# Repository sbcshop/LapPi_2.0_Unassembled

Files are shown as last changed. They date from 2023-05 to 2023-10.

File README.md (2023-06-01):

# LapPi_2.0_Unassembled


LapPi 2.0 - a 100% DIY modular laptop which is compatible with all single board computers. Now that's what we call a true Level-Up.

LapPi 2.0 is in its core is a superbly loaded computer, one of its kind and only one in such segment. Available in 5 bright (Clear, Red, Blue, Yellow and Black) and beautiful colors, LapPi 2.0 comes in assembled and un-assembled variants.

The users may choose any single board computer (SBC) for LapPi such as RockPi, Asus Tinker, BananaPI or RaspberryPi. Just connect the SBC and voilà.

LapPi 2.0 is available in 2 variants - **_Assembled_** and **_Unassembled_**. 

You can checkout Step by Step Guide for **_Assembled version of LapPi 2.0_ [here](https://github.com/sbcshop/LapPi_2.0_Assembled)** 

The unassembled version is a treat for our techie friends and electronic enthusiasts. As we mentioned, LapPi 2.0 is 100% 'Do It Yourself', you get all the components and parts in individual packing in a classy protective case. Assembly of the LapPi 2.0 is very easy.

### Box Content
- 13 x 3mm thick Acrylic Panels
- 02 x Hinges
- 02 x 8ohm Speakers
- 01 x Raspberry Pi Official 8MP NoIR Camera
- 01 x Micro USB Power Cable
- 01 x Type C Power Cable
- 01 x Micro HDMI Connector
- 02 x HDMI Connector
- 01 x HDMI Flex Cable
- 01 x 7 inch Full Touch Capacitive LCD
- 01 x UPS (without batteries)
- 01 x Wireless Keyboard
- 01 x Power Adapter
- 01 x Pack of Screws and Standoffs
- 01 x Protective Case

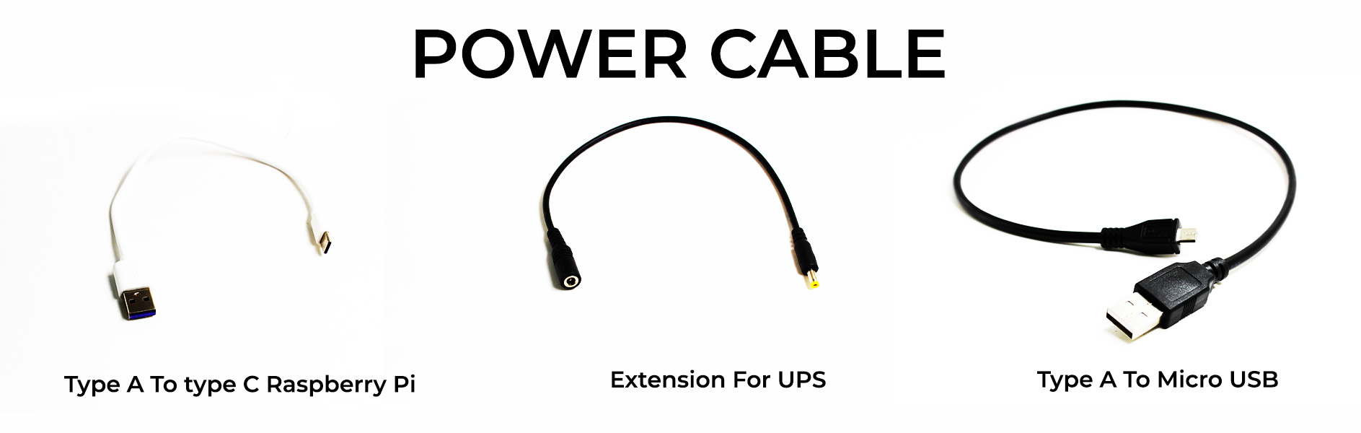
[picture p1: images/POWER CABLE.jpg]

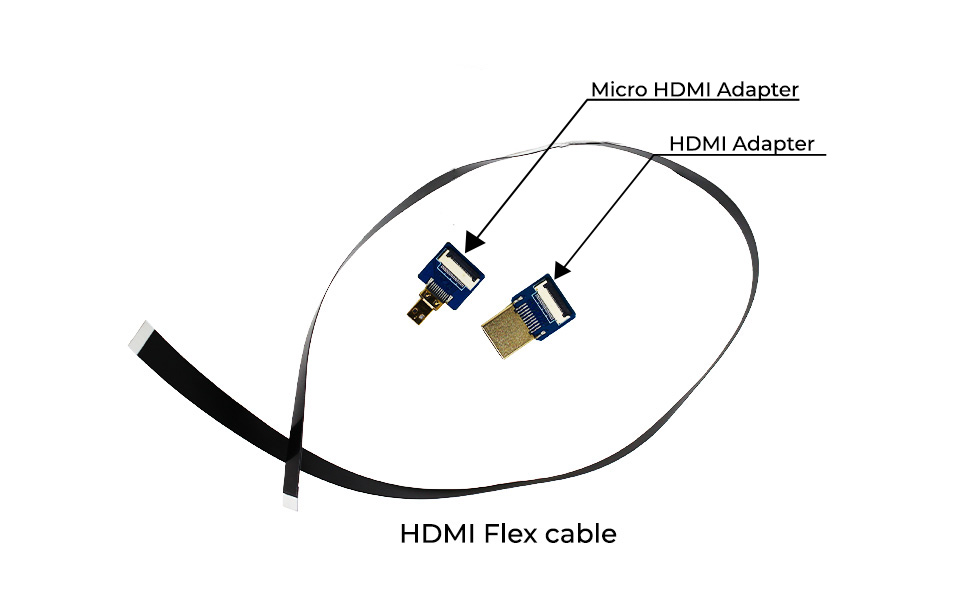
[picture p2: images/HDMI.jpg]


### Prepare HDMI Extension cable 


## Step 1: Setup Raspberry Pi
Before we begin assembling the LapPi, let us first set up the Raspberry Pi, which you may do by following the latest Online [Raspberry Pi Setup instructions](https://projects.raspberrypi.org/en/projects/raspberry-pi-setting-up)

Or [Click Here](https://github.com/sbcshop/LapPi_2.0_Unassembled/blob/main/Documents/Setting%20up%20your%20Raspberry%20Pi.pdf) to download a pdf of how to set up Pi.

## Step 2: Assembly Process
Before we proceed for assembly make sure you have below listed Screws, nuts and standoff in mentioned qty required for various section of LapPi assembly,

* For Body: (Qty - 28 set)
  * Screw - M3x10mm
  * Nut- M3
 
* For KeyBoard: (Qty - 5 set) 
  * Standoff - M3x12mm
  * Screw - M3x10mm
  * Nut - M3

* For Camera: (Qty - 4 set) 
  * Screw - M1.5x10mm
  * Nut - M1.5

* For Display: (Qty - 4 set) 
  * Standoff - M3x12mm
  * Screw - M3x10mm
  * Nut - M3

* For Raspberry Pi & UPS Hat: (Qty - 8 set) 
  * Standoff - M2.5x12mm
  * Screw - M2.5x10mm
  * Nut - M2.5

* For Speaker: (Qty - 8 set)
  * Standoff - M3x24mm
  * Nut - M3

* For Hinge : (Qty - 8 set)
  * Screw Self-Taping - M3x6mm

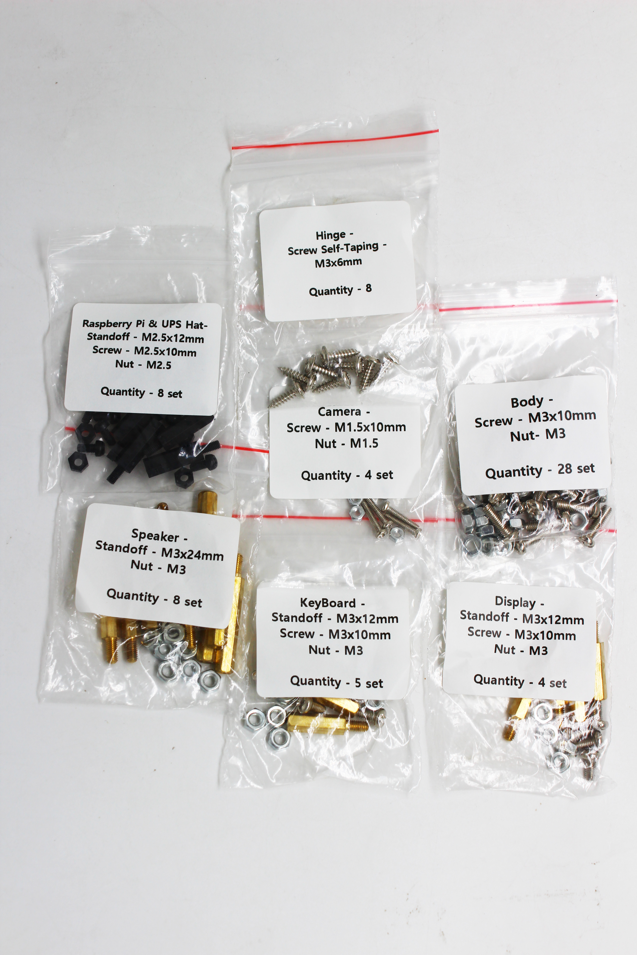
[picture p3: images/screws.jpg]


Checkout below demo to understand working with screw and nuts fitting,

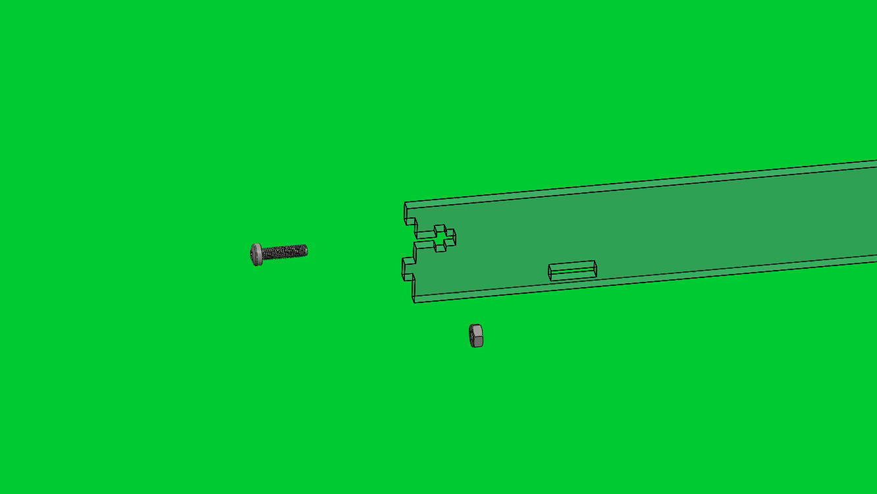
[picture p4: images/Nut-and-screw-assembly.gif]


### 1) LapPi 2.0 Base Part Assembly: 
- Here in base assembly section will be dealing with some acrylic body parts like Base plate and side layers, for this you will need M3x10mm Screw, M3 Nut
- First you will place UPS power and Raspberry Pi using mentioned sets of standoff, screw and nuts. 
- Next you will attach side layer plus support layer for keyboard.

Checkout demo below for better understanding how to achieve this section of assembly:

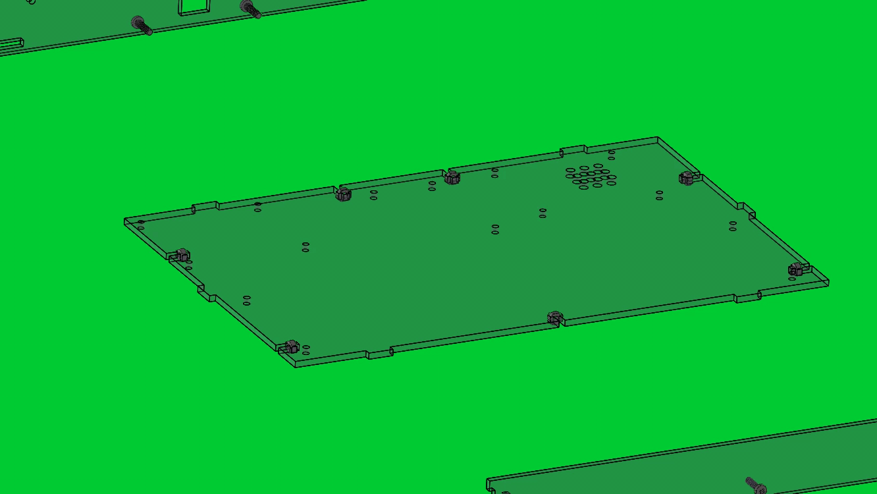
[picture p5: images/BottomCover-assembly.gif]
 

### 2) LapPi 2.0 Top Part Assembly:
- In this section will be dealing with display, camera and speaker fittings. 
- Again first take base support plate attach display and speaker.
- Then connect side layer plus top support layer on which camera will be attach  
So checkout below steps to follow,

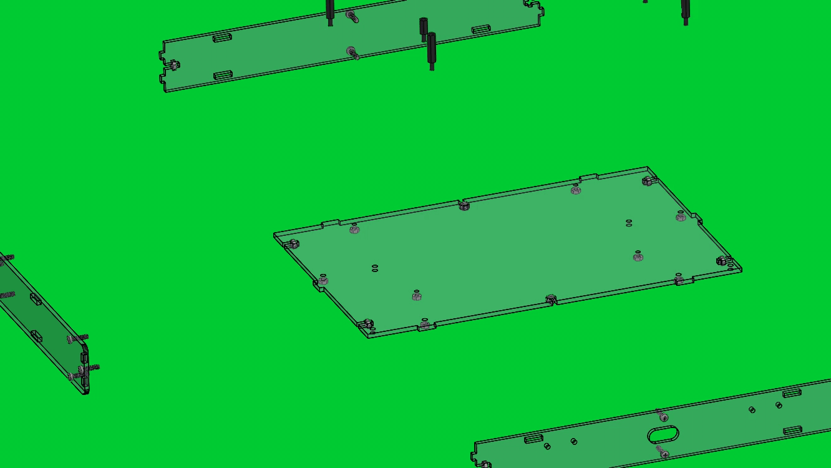
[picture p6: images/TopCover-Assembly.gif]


### 3) Combine top and bottom parts together with hinge:
- Finally will be attaching Top and Bottom section of assembly together with hinge as shown below:

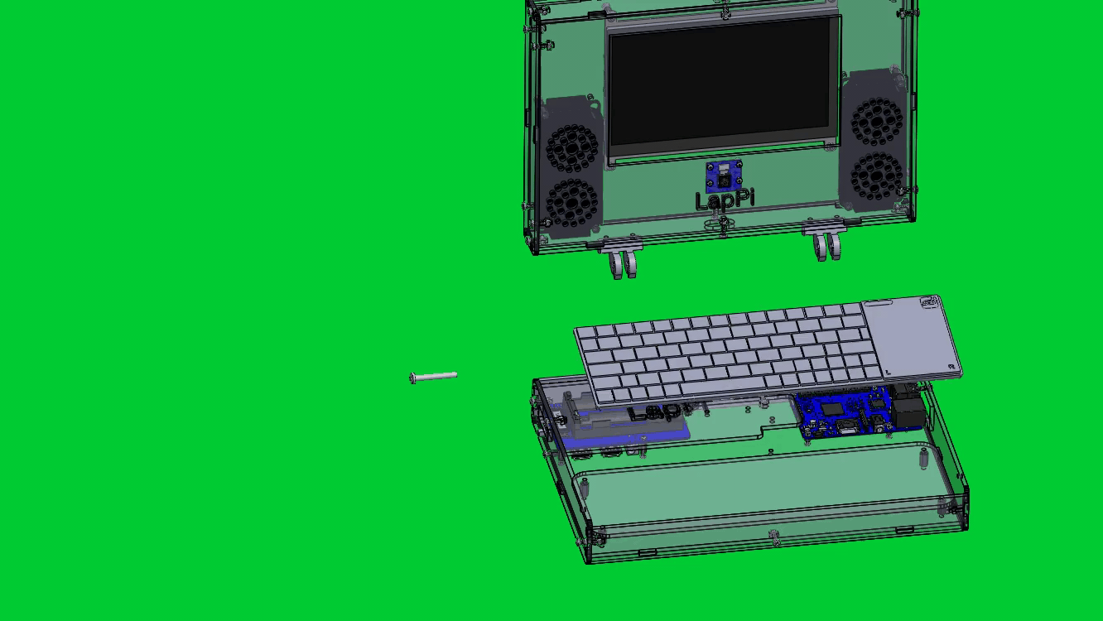
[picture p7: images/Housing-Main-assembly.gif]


Check out this one-shot video of the entire LapPi 2.0 assembly procedure :

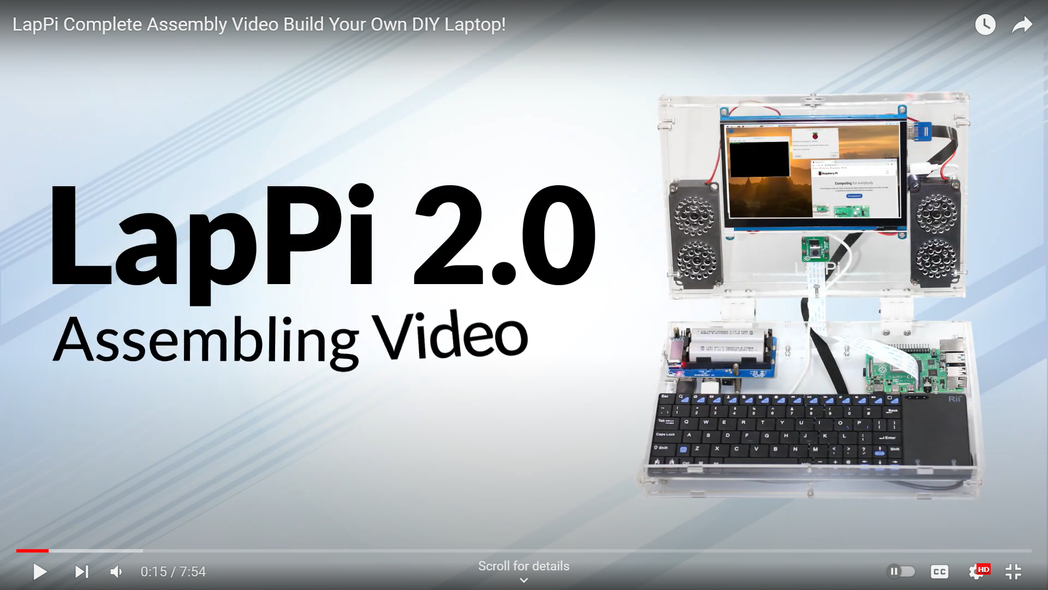
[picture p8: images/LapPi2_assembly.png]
Watch the video (https://www.youtube.com/watch?v=cyu9svhStYQ)


## Related Products
   * [UPS HAT (Uninterrupted Power Supply)](https://shop.sb-components.co.uk/products/ups-hat-for-raspberry-pi?_pos=4&_sid=f735813a1&_ss=r) -Power backup to save the Raspberry Pi during power outages or unintentional shutdowns
   
     UPS_HAT_Pi
   
   * [Raspberry Pi 4 Model B 4GB kit](https://shop.sb-components.co.uk/products/raspberry-pi-4-model-b-4gb-kit?_pos=6&_sid=1e4720b41&_ss=r) - the ultimate solution for all your DIY computing needs! This kit comes packed with all the essential components you need to start building your own projects right away.
   
     Pi4_modelB_4GB
   
   * [7" LCD screen](https://shop.sb-components.co.uk/products/7-hdmi-lcd-h-1024x600-ips-capacitive-touch-screen-lcd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) - 7inch, IPS, 1024x600, Capacitive Touch Screen LCD with Toughened Glass Cover, Supports Raspberry Pi, and can also be used as a computer monitor.
   
     7inch_LCD
   
## Product License

This is ***open source*** product. Kindly check LICENSE.md file for more information.

Please contact support@sb-components.co.uk for technical support.
<p align="center">
  
</p>

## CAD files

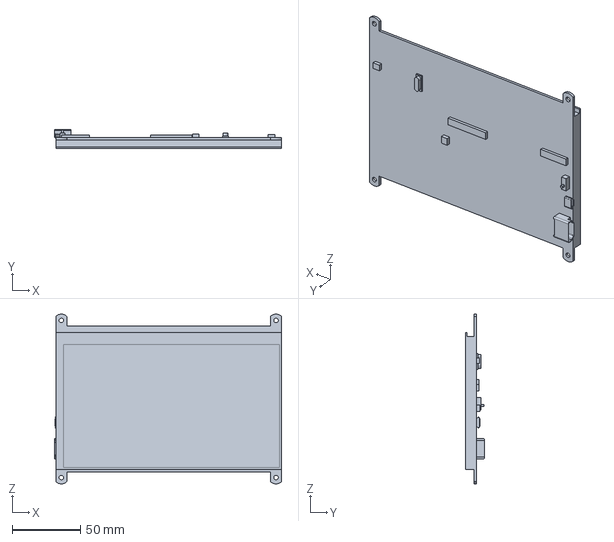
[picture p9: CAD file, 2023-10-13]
Documents/7inchLCD.stp
166.0 x 14.1 x 124.1 mm
